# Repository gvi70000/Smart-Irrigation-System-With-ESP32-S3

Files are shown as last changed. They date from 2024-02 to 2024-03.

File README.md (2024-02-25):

Introducing the Smart Irrigation System Controller Board powered by the ESP32-S3!
Water-Automation-PCB-Top

Water-Automation-PCB-Bottom

This hardware combines innovation and efficiency to revolutionize the way you manage your irrigation needs. Equipped with a host of advanced features, including an onboard BMP581 for precise weather data, support for up to 10 valve controls via relays, and seamless serial communication with a VL53L4CX sensor to accurately measure water levels in your well, this controller board is your key to achieving optimal irrigation and conserving valuable resources.

Say goodbye to guesswork and hello to intelligent, data-driven irrigation management, Welcome to the future of smart agriculture.

This feature-packed ESP32-S3-based Smart Irrigation System Controller Board is designed to streamline your irrigation management with unparalleled precision and control.

The board serves as the central hub for your irrigation system, seamlessly connecting and communicating with MQTT servers for efficient operation.

With 10 GPIO pins at your disposal, capable of driving up to 10 relays through 3V3 to 5V level shifters, you can effortlessly control the water flow in your irrigation system. The status of each output is visually presented using dedicated LEDs (L1 to L10 pins), providing real-time feedback to keep you informed.

For manual control of your valves, we've incorporated an analog input to read an array of push buttons. The voltage divider for the button array is thoughtfully designed for easy interfacing and intuitive operation.

The board also integrates Serial Port 1 of the ESP32-S3 to communicate with a VL53L4CX Time-Of-Flight sensor. This sensor plays a crucial role in monitoring water levels in your main reservoir or well, ensuring they remain within safe limits. The communication between the ESP32-S3 and the VL53L4CX is facilitated via an STM32F103 microcontroller, enhancing its capabilities. Notably, the power to the sensor is intelligently managed by the ESP32-S3 program to conserve energy.

To provide comprehensive environmental data, I've included a BMP581 pressure and temperature sensor on the I2C port. This allows you to access essential information such as atmospheric pressure and temperature. Additionally, the I2C port is open for additional device connections, provided that the I2C pull-up resistors are located on this controller board for your convenience.

For situations demanding higher current, the board offers a controlled output switch on S25V, directly connected to the 5V onboard power supply.

When it comes to programming, you have the flexibility to choose between the USB C port or the ESP32-S3 Serial Port 0 (Tx, Rx, 3V3, GND pins), making the process straightforward and accessible.

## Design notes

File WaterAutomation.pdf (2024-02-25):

# Water Automation Control

## Made by Ion Grozea

www.grozeaion.com

# Components

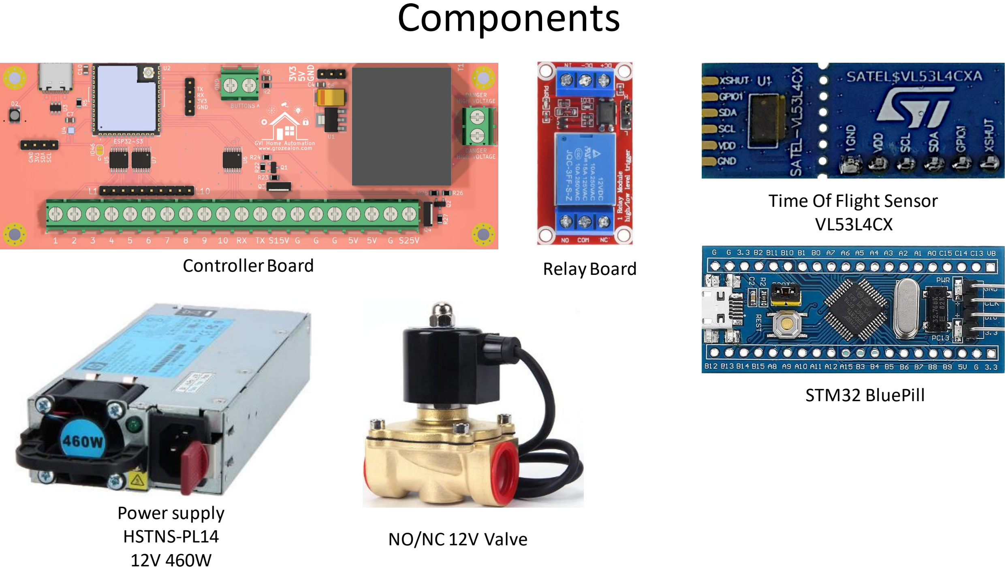
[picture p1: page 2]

Power supply
HSTNS-PL14
12V 460W

NO/NC 12V Valve

Time Of Flight Sensor
VL53L4CX

STM32 BluePill

Controller Board | Relay Board

# Components

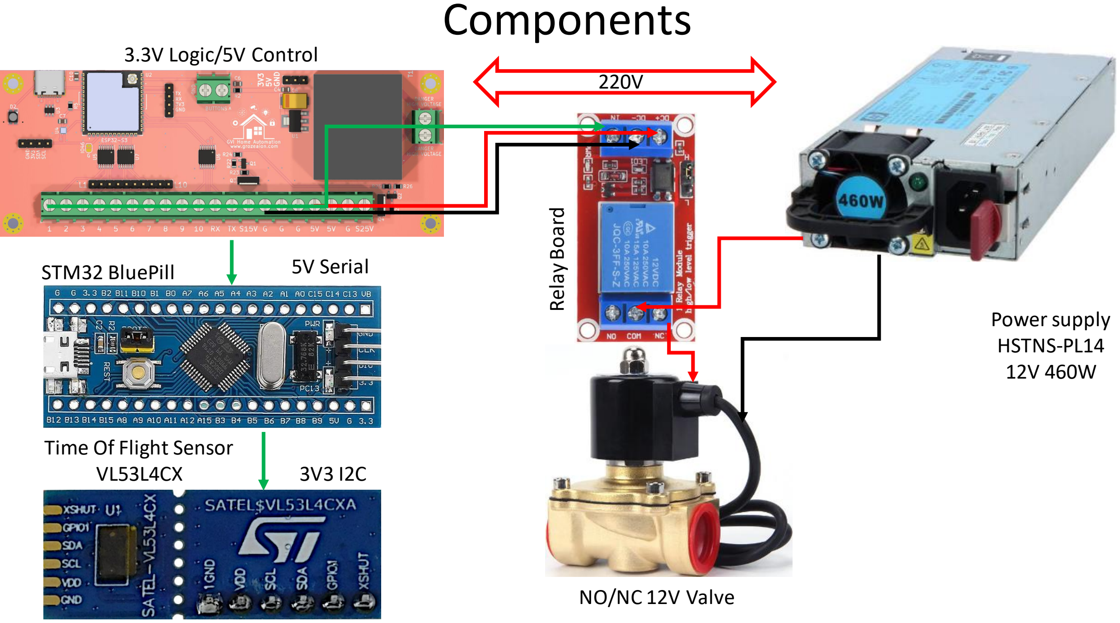
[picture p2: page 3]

Power supply
HSTNS-PL14
12V 460W

NO/NC 12V Valve

Time Of Flight Sensor
VL53L4CX

5V Serial

Relay Board

3.3V Logic/5V Control
220V

STM32 BluePill

3V3 I2C

# Controller PCB Top

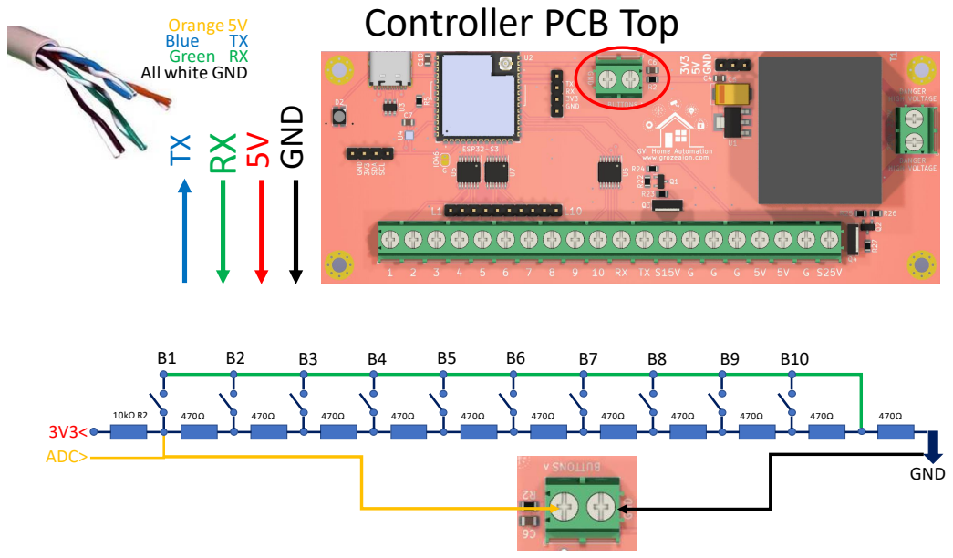
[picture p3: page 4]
GND; Blue; 3V3< ADC>

Orange 5V
Green RX
All white GND

# Controller PCB Top

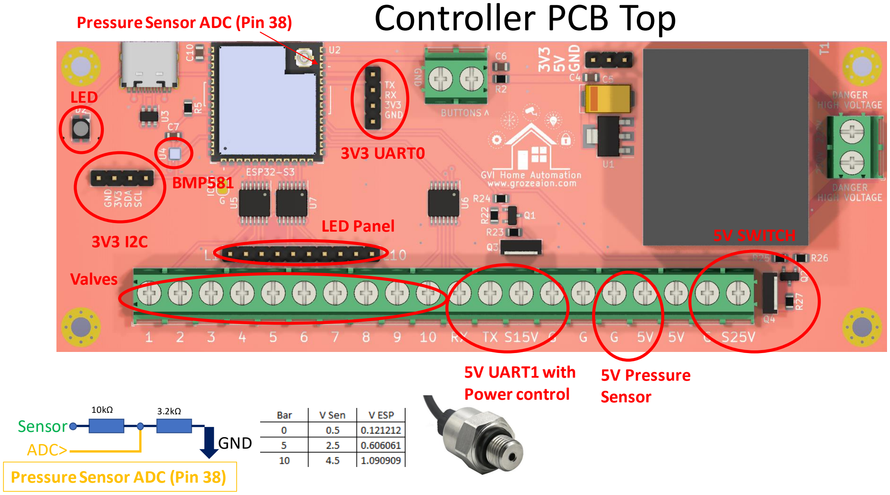
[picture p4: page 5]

3V3 I2C

3V3 UART0
BMP581

LED

LED Panel | 5V SWITCH

Valves

5V UART1 with
Power control
10kΩ | 3.2kΩ
Sensor
ADC> | GND

Pressure Sensor ADC (Pin 38)

Pressure Sensor ADC (Pin 38)

5V Pressure
Sensor

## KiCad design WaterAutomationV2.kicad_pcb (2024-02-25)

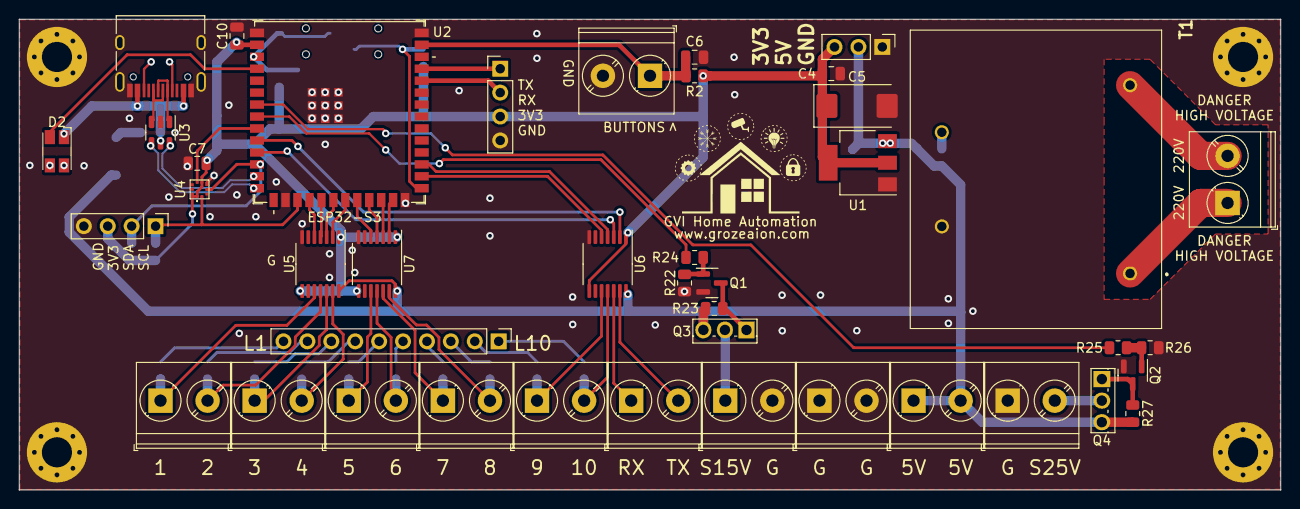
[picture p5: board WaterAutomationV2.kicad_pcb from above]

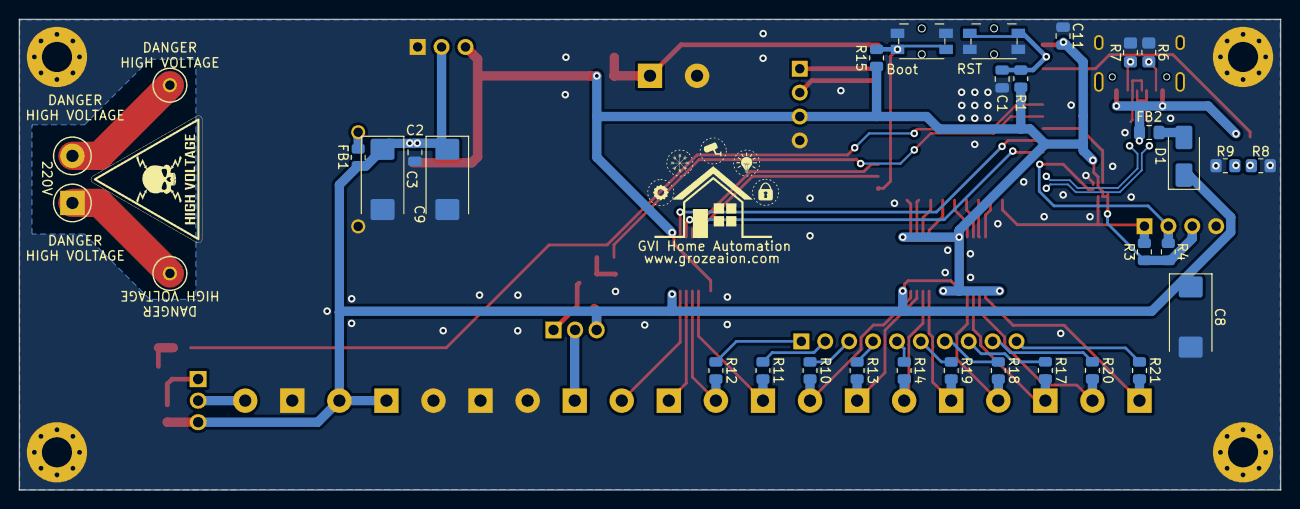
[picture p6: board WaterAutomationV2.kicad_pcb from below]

Board: 2 copper layers, 134.0 x 50.0 mm, 75 parts (29 on the bottom side), 67 nets.

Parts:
C1, C2, C4, C7, C10: 100n; C_0805_2012Metric
C3, C5, C8, C9: 22u; CP_EIA-7343-43_Kemet-X_Pad2.25x2.55mm_HandSolder
C6: C; C_0805_2012Metric
C11: 10u; C_0805_2012Metric
D1: MBRA340; D_SMA
D2: LED_Dual_AKKA; LED_Avago_PLCC4_3.2x2.8mm_CW
FB1: FerriteBead; R_0805_2012Metric
FB2: FerriteBead; C_0805_2012Metric_Pad1.18x1.45mm_HandSolder
H2, H3, H4, H5: MountingHole_Pad; MountingHole_3.2mm_M3_Pad_Via
J1, J3, J5, J7, J9, J10, J11, J13, J15, J17, J19, J20: Screw_Terminal_01x02; TerminalBlock_Phoenix_PT-1,5-2-5.0-H_1x02_P5.00mm_Horizontal
J2, J4: Conn_01x04; PinHeader_1x04_P2.54mm_Vertical
J6: Conn_01x03; PinHeader_1x03_P2.54mm_Vertical
J12: Conn_01x10; PinHeader_1x10_P2.54mm_Vertical
Q1, Q2: BSS138; SOT-23
Q3, Q4: IRFU9024NPBF; TO-251-3_Vertical
R1, R2, R15, R22, R23, R26, R27: 10k; R_0805_2012Metric
R3, R4: 2.2k; R_0805_2012Metric
R6, R7: 5.1k; R_0805_2012Metric_Pad1.20x1.40mm_HandSolder
R8: 100; R_0805_2012Metric_Pad1.20x1.40mm_HandSolder
R9: 220; R_0805_2012Metric_Pad1.20x1.40mm_HandSolder
R10, R11, R12, R13, R14, R17, R18, R19, R20, R21: 220; R_0805_2012Metric
R24, R25: 100; R_0805_2012Metric
SW1: RST; Panasonic_EVQPUM_EVQPUD
SW2: Boot; Panasonic_EVQPUM_EVQPUD
T1: 47152; MYRRA-47121
U1: LD1117S12TR_SOT223; SOT-223-3_TabPin2
U2: ESP32-S3-WROOM-1; ESP32-S3-WROOM-1U
U3: USBLC6-2SC6; SOT-23-6
U4: BMP581
U5, U6, U7: TXS0104E; TSSOP-14_4.4x5mm_P0.65mm
USB1: USB C; USB_C_Receptacle_HRO_TYPE-C-31-M-12

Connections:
+3.3V: C4.1, C5.1, C7.1, C10.1, C11.1, J2.3, J4.3, J6.3, R1.2, R2.1, R3.2, R4.2, R15.1, U1.2 (VO), U2.2 (3V3), U4.1 (VDDIO), U4.6 (CSB), U4.10 (VDD), U5.1 (VCCA), U5.8 (OE), U6.1 (VCCA), U6.8 (OE), U7.1 (VCCA), U7.8 (OE)
+5V: C2.1, C3.1, C8.1, C9.1, D1.1 (K), FB1.1, J6.2, J10.1, J10.2, Q3.3 (SOURCE), Q4.3 (SOURCE), R23.1, R27.1, U1.3 (VI), U5.14 (VCCB), U6.14 (VCCB), U7.14 (VCCB)
+5VD: D2.1 (A1), FB2.1, U3.5 (VBUS), USB1.A4 (VBUS), USB1.A9 (VBUS), USB1.B4 (VBUS), USB1.B9 (VBUS)
BOOT: R15.2, SW2.2, U2.27 (GPIO0/BOOT)
BUTTONS: C6.1, J5.1, R2.2, U2.39 (GPIO1/TOUCH1/ADC1_CH0)
CTRL_SEN1: R24.1, U2.8 (GPIO15/U0RTS/ADC2_CH4/XTAL_32K_P)
CTRL_SEN2: R25.1, U2.7 (GPIO7/TOUCH7/ADC1_CH6)
GND: C1.2, C2.2, C3.2, C4.2, C5.2, C6.2, C7.2, C8.2, C9.2, C10.2, C11.2, H2.1, H3.1, H4.1, H5.1, J1.1, J2.4, J4.4, J5.2, J6.1, J7.1, J7.2, J19.2, Q1.2 (S), Q2.2 (S), R6.1, R7.1, R8.1, R9.1, R22.1, R26.1, SW1.2, SW2.1, T1.9 (DC_OUTPUT_0V), U1.1 (GND), U2.1 (GND), U2.16 (GPIO46), U2.26 (GPIO45), U2.40 (GND), U2.41 (GND), U3.2 (GND), U4.3 (VSS_1), U4.5 (SDO), U4.8 (VSS_2), U4.9 (VSS_3), U5.7 (GND), U6.7 (GND), U7.7 (GND), USB1.A1 (GND), USB1.A12 (GND), USB1.B1 (GND), USB1.B12 (GND), USB1.S1 (Shell1)
INT: U2.9 (GPIO16/U0CTS/ADC2_CH5/XTAL_32K_N), U4.7 (INT)
LED: D2.4 (A2), U2.4 (GPIO4/TOUCH4/ADC1_CH3)
unnamed: D1.2 (A), FB2.2
unnamed: D2.2 (K1), R9.2
unnamed: D2.3 (K2), R8.2
unnamed: J3.1, T1.1 (AC_OR_DC_INPUT_1)
unnamed: J3.2, T1.5 (AC_OR_DC_INPUT_2)
unnamed: J12.1, R12.1
unnamed: J12.2, R11.1
unnamed: J12.3, R10.1
unnamed: J12.4, R13.1
unnamed: J12.5, R14.1
unnamed: J12.6, R19.1
unnamed: J12.7, R18.1
unnamed: J12.8, R17.1
unnamed: J12.9, R20.1
unnamed: J12.10, R21.1
unnamed: Q1.3 (D), Q3.1 (GATE), R23.2
unnamed: Q1.1 (G), R22.2, R24.2
unnamed: Q2.3 (D), Q4.1 (GATE), R27.2
unnamed: Q2.1 (G), R25.2, R26.2
unnamed: FB1.2, T1.7 (DC_OUTPUT_+V)
unnamed: U3.1 (I/O1), USB1.A7 (D-), USB1.B7 (D-)
unnamed: U3.3 (I/O2), USB1.A6 (D+), USB1.B6 (D+)
unnamed: R7.2, USB1.A5 (CC1)
unnamed: R6.2, USB1.B5 (CC2)
O1: J9.1, R21.2, U5.10 (B4)
O2: J9.2, R20.2, U5.11 (B3)
O3: J11.1, R17.2, U5.12 (B2)
O4: J11.2, R18.2, U5.13 (B1)
O5: J13.1, R19.2, U7.10 (B4)
O6: J13.2, R14.2, U7.11 (B3)
O7: J15.1, R13.2, U7.12 (B2)
O8: J15.2, R10.2, U7.13 (B1)
O9: J17.1, R11.2, U6.10 (B4)
O10: J17.2, R12.2, U6.11 (B3)
PWR_SEN1: J19.1, Q3.2 (DRAIN)
PWR_SEN2: J1.2, Q4.2 (DRAIN)
RST: C1.1, R1.1, SW1.1, U2.3 (EN)
RX0: J2.2, U2.36 (U0RXD/GPIO44/CLK_OUT2)
RX1: U2.11 (GPIO18/U1RXD/ADC2_CH7/CLK_OUT3), U6.3 (A2)
RX05: J20.1, U6.12 (B2)
SCL: J4.1, R3.1, U2.17 (GPIO9/TOUCH9/ADC1_CH8/FSPIHD/SUBSPIHD), U4.2 (SCK)
SDA: J4.2, R4.1, U2.12 (GPIO8/TOUCH8/ADC1_CH7/SUBSPICS1), U4.4 (SDI)
TX0: J2.1, U2.37 (U0TXD/GPIO43/CLK_OUT1)
TX1: U2.10 (GPIO17/U1TXD/ADC2_CH6), U6.2 (A1)
TX05: J20.2, U6.13 (B1)
USB_D+: U2.14 (GPIO20/U1CTS/ADC2_CH9/CLK_OUT1/USB_D+), U3.4 (I/O2)
USB_D-: U2.13 (GPIO19/U1RTS/ADC2_CH8/CLK_OUT2/USB_D-), U3.6 (I/O1)
V1: U2.18 (GPIO10/TOUCH10/ADC1_CH9/FSPICS0/FSPIIO4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), U5.5 (A4)
V2: U2.19 (GPIO11/TOUCH11/ADC2_CH0/FSPID/FSPIIO5/S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), U5.4 (A3)
V3: U2.20 (GPIO12/TOUCH12/ADC2_CH1/FSPICLK/FSPIIO6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), U5.3 (A2)
V4: U2.21 (GPIO13/TOUCH13/ADC2_CH2/FSPIQ/FSPIIO7/S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), U5.2 (A1)
V5: U2.22 (GPIO14/TOUCH14/ADC2_CH3/FSPIWP/FSPIDQS/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), U7.5 (A4)
V6: U2.23 (GPIO21), U7.4 (A3)
V7: U2.24 (GPIO47/SPICLK_P/SUBSPICLK_P_DIFF), U7.3 (A2)
V8: U2.25 (GPIO48/SPICLK_N/SUBSPICLK_N_DIFF), U7.2 (A1)
V9: U2.28 (SPIIO6/GPIO35/FSPID/SUBSPID), U6.5 (A4)
V10: U2.29 (SPIIO7/GPIO36/FSPICLK/SUBSPICLK), U6.4 (A3)

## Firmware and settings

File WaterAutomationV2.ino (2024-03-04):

#include <Wire.h>
#include <EEPROM.h>
#include <WiFi.h>
#include <PubSubClient.h>
#include "SparkFun_BMP581_Arduino_Library.h"

// Use it for printing messages
//#define DEBUG

// If we use the water pressure sensor to monitor pressure and leaks
//#define HAS_PRESSURE

// Control valve if a leak is detected
//#define HAS_LEAK_CONTROL

#if defined DEBUG
   #define debug_begin(x) Serial.begin(x)
   #define debug(x)       Serial.print(x)
   #define debugln(x)     Serial.println(x)
#else
   #define debug_begin(x)
   #define debug(x)
   #define debugln(x)
#endif

// We have 3 or 4 sensors?
#ifdef HAS_PRESSURE
  constexpr uint8_t SENSORS_NO      = 4;
#else
  constexpr uint8_t SENSORS_NO      = 3;
#endif

// 388 bytes for calibration, 1 byte for C(alibration), 1 byte checksum, 2 bytes start/end message marker
// 388 bytes for calibration, 1 byte for C(alibration), 1 byte checksum, 2 bytes start/end message marker
constexpr uint16_t CALIB_DATA_LEN   = 388;
// Buffer length Tx and Rx
constexpr uint16_t BUFFER_LEN	= CALIB_DATA_LEN + 4;
// Max. no. of devices
constexpr uint8_t DEV_MAX           = 10;
// Where in EEPROM we start to store calibration data
constexpr uint8_t CAL_START         = DEV_MAX + 1; // Pos 11
// Where in EEPROM we stop to store calibration data
constexpr uint16_t CAL_END          = CAL_START + CALIB_DATA_LEN; // Pos 38

// Used in serial communication with VL sensor
constexpr uint8_t START_MARKER		  = 60; // < Start marker for serial
constexpr uint8_t END_MARKER			  = 62; // > End marker for serial
constexpr uint8_t CMD_CALIBRATE		  =	67; // Send C to start calibration
constexpr uint8_t CMD_STORE_CAL		  =	83; // Send S to store calibration data we send

constexpr uint8_t RESPONSE_LENGTH	  = 76; // Get L to inform about length data
constexpr uint8_t RESPONSE_CAL_DONE	= 67; // Get C to inform about calibration data
constexpr uint8_t RESPONSE_FAIL		  = 70; // Get F to indicate something went wrong
constexpr uint8_t RESPONSE_OK			  = 83; // CMD_STORE_CAL // Get S to indicate something went OK

#ifdef HAS_PRESSURE
// 4.5v 4,7k 1.47k 1.072V
  //constexpr float ADC_FACTOR      0.000805664062f
  constexpr float VOLT_TO_BAR_F1    = 0.008308813477f; // This is 10.313f * ADC_FACTOR
  constexpr float VOLT_TO_BAR_F2    = 1.25f;
  constexpr uint8_t PRESS_PIN       = 2; // Analog read Pressure
  // R1 = 9.95, R2=3.264 => 1.112V from 4.5V
  // P = 0.0024 * ADC
#endif
// Pins used
constexpr uint8_t BTN_PIN           = 1; // Analog read buttons
constexpr uint8_t LED_PIN           = 4;
constexpr uint8_t LEVEL_PIN         = 7;
constexpr uint8_t CTRL_PIN2         = 15;

// WiFi Connect period in ms
constexpr uint16_t UART_SPEED        = 9600;
// WiFi Connect period in ms
constexpr uint16_t WiFi_Period       = 1000;
// Send data to MQTT brocker every 30 seconds
constexpr uint16_t mqttPeriod       = 10; 
// Min. water level in the well in m
constexpr float minWellLevel        = 0.5;
// Delay for MQTT functions
constexpr uint8_t delayMQTT         = 50;
// WiFi Connect period
constexpr uint16_t VL53L4CX_WAIT    = 6000;
// Debounce time in milliseconds
constexpr uint8_t DEBOUNCE_DELAY    = 100;

// ADC Values for buttons 1 to 10
constexpr uint16_t BTN_ADC_MIN[] = {430, 870, 1280, 1650, 1990, 2315, 2615, 2895, 3155, 3400};
constexpr uint16_t BTN_ADC_MAX[] = {470, 830, 1320, 1690, 2030, 2355, 2655, 2935, 3195, 3440};

enum Button { None, Btn1, Btn2, Btn3, Btn4, Btn5, Btn6, Btn7, Btn8, Btn9, Btn10 };
enum DeviceStatus { Off, On };
enum SensorNumber { Level, Temp, Press, WaterPress};

typedef struct ButtonObject {
  const char* topicState;
  const char* topicTime;
  uint8_t pin;
  uint8_t pinState;
  uint8_t timeTarget;
  volatile uint16_t timeSeconds;
};

typedef struct SensorObject {
  const char* name;
  float val;
};

#ifdef HAS_LEAK_CONTROL
  ButtonObject myBackUp[2];
#endif
ButtonObject myDevices[DEV_MAX];
SensorObject mySensors[SENSORS_NO];

// MQTT Server IP
const char* mqtt_server		= "XXX.XXX.XXX.XXX";
// MQTT Server username
const char* mqtt_username	= "MQTT_USER";
// MQTT Server password
const char* mqtt_password = "MQTT_PASSWORD";
// Client name
const char* clientID      = "Valves";
// Number of devices to be used
const char* maxDevNo      = "water/MaxDevNo";
// Calibration topic
constexpr char *topic_CalDist = "Level/Calibrate";
#ifdef HAS_LEAK_CONTROL
  // Leak alarm topic
  constexpr char *topic_LeakAlarm = "water/LeakAlarm";
  // Pressure drop value for alarm in Bar
  constexpr char *topic_LeakValue = "water/LeakValue";
#endif
// MQTT Server port
constexpr uint16_t MQTT_Port   = 1883;

volatile uint8_t interruptBMP = 0;

// Array stored in RTC memory to hold:
// 0-9 Time for each device in Min, 10 Maximum number of devices used
uint8_t DEV_IN_USE = 1;

// Stores the time when the sensors must be read
volatile uint16_t mqttTime;

// Current button
uint8_t crtButton = None;
// Timer
hw_timer_t * timer = NULL;
// Calibration Distance
uint8_t calibrateDistance = 0;
// Used for timeout
uint32_t timeCheck;
#ifdef HAS_LEAK_CONTROL
  // Store the alarm status
  uint8_t alarmLeak = 0;
  // Store the last pressure reading
  float prevPressureVal = 0.0f;
  // If pressure drops with 1 Bar the alarm is raised
  float pressureThreshold = 1.0f; 
#endif

BMP581 pressureSensor;
WiFiClient wifi_Client;
PubSubClient mqtt_Client(wifi_Client);

// Interrupt callback function for timer
void IRAM_ATTR onTimer() {
  mqttTime++;
  for (int cnt = 0; cnt < DEV_IN_USE; cnt++) {
    // If the device is On, increment the timer
    if(myDevices[cnt].pinState) {
      myDevices[cnt].timeSeconds++;
    }
  }
}

// Interrupt callback function for BMP581
void bmp581InterruptHandler() {
  interruptBMP = 1;
}

void sendToSTM(const uint8_t msgType) {
  uint16_t txLen = 4;
  // Determine the message length and fill the buffer based on message type
  if(msgType == CMD_STORE_CAL) {
    txLen = BUFFER_LEN;
  }
  uint8_t txBuffer[txLen];
  // Initialize the common header for all messages
  txBuffer[0] = START_MARKER;
  txBuffer[1] = msgType;
  uint8_t checkSum = msgType;
  if(msgType == CMD_STORE_CAL) {
    for (uint16_t cnt = CAL_START; cnt < CAL_END; cnt++) {
      uint16_t tmp = cnt - 9;
      txBuffer[tmp] = EEPROM.read(cnt);
      checkSum += txBuffer[tmp];
    }
  }
  // Add checksum and end marker
  txBuffer[txLen - 2] = checkSum;
  txBuffer[txLen - 1] = END_MARKER;
  // Send the message
  Serial1.write(txBuffer, txLen);
}

uint8_t ProcessReceivedMessage() {
  digitalWrite(LED_PIN, LOW);
  uint8_t retunValue = 0;
  // If we have 4 bytes in the buffer and the first one is <
  if((Serial1.available() > 3) && (Serial1.read() == START_MARKER)) {
    // Get the message type
    uint8_t msgType = Serial1.read();
    // Keep in mind that we already read 2 bytes
    // Depending on message type we need to wait for some more bytes
    uint16_t expectedMsgLen = 0; 
    // expectedMsgLen in below switch is ignoring the last 2 bytes we receive
    switch(msgType) {
      case RESPONSE_LENGTH: // We get 6 bytes in total
        expectedMsgLen = 2;
      break;
      case RESPONSE_CAL_DONE: // We get 392 bytes in total
        expectedMsgLen = CALIB_DATA_LEN;
      break;
      default: // RESPONSE_OK, RESPONSE_FAIL // We get 4 bytes in total
        expectedMsgLen = 0;
      break;
    }

    uint8_t receivedCheckSum = 0;
    // If we get a 4 byte message < M M >
    // The third byte we read is the checkSum
    if(!expectedMsgLen) {
      receivedCheckSum = Serial1.read();
      if(receivedCheckSum == msgType) {
        retunValue = msgType;
      }
    } else {
      // Wait to receive all bytes or return timeout
      timeCheck = millis();
      while(Serial1.available() < expectedMsgLen) {
        // If we have a timeout, exit the function
        if((millis() - timeCheck) > VL53L4CX_WAIT) {
          // Reuse timeCheck 
          timeCheck = 0;
          break;
        }
      }
      // If we do not have a timeout
      if(timeCheck) {
        // Buffer to hold received values, START_MARKER not included
        uint8_t rxBuffer[expectedMsgLen];
        // Add message type as it is needed in check sum calculation
        uint8_t checksum = msgType;
        // Add all bytes in the buffer and calculate check sum in the same loop
        for (uint16_t i = 0; i < expectedMsgLen; i++) {
          rxBuffer[i] = Serial1.read();
          // Calculate the check sum
          checksum += rxBuffer[i];
          // Serial.print(i); Serial.print(">>>"); Serial.println(rxBuffer[i]);
        }
        // By now we have received the last 2 bytes
        receivedCheckSum = Serial1.read();
        // Do not check for > end marker as we test the check sum 
        // Check message validity
        if (checksum == receivedCheckSum) {
          // What type of message we have?
          switch (msgType) {
            case RESPONSE_OK:
              retunValue = RESPONSE_OK;
            break;
            case RESPONSE_FAIL:
              // Handle failure response
              retunValue = RESPONSE_FAIL;
            break;
            case RESPONSE_LENGTH:
              // Process length data
              {
              mySensors[Level].val = (float)*(uint16_t*)&rxBuffer[0];
              retunValue = RESPONSE_LENGTH;
              }
            break;
            case RESPONSE_CAL_DONE:
            {
              // Process calibration data. From 0 to DEV_MAX we have the device data
              for(uint16_t cnt = CAL_START; cnt < CAL_END; cnt++) {
                EEPROM.write(cnt, rxBuffer[cnt - CAL_START]);
                // Serial.print(cnt);Serial.print("---");Serial.print(cnt - CAL_START);
                // Serial.print("---");Serial.println(rxBuffer[cnt - CAL_START]); 
              }
              // No need to wait after commit
              EEPROM.commit();
              retunValue = RESPONSE_CAL_DONE;
            }
            break;
          } // End switch
        } // End CheckSum check
      } // End timeout check
    } // End longer message check
  }
  digitalWrite(LED_PIN, HIGH);
  Serial1.flush();
  return retunValue;
}

// Signal errors error
void ledSignal(uint8_t err) {
  // Delay for MQTT functions
  constexpr uint8_t stateDelay = 250;
  uint8_t blinkCnt = 0;
  switch(err) {
    case 1:
      blinkCnt = 3;
      break;
    case 2:
      blinkCnt = 4;
      break;
    default:
      blinkCnt = 2;
  }
  for(uint8_t c = 0; c < blinkCnt; c++){
    digitalWrite(LED_PIN, HIGH);
    delay(stateDelay);
    digitalWrite(LED_PIN, LOW);
    delay(stateDelay);
  }
}

void writeDefaultEEPROM() {
  for(uint8_t cnt = 0; cnt < DEV_MAX; cnt++) {
    EEPROM.write(cnt, 0);
  }
  EEPROM.write(DEV_MAX, 1);
  EEPROM.commit();
  delay(delayMQTT);
}

void setup() {
  constexpr uint8_t TX1_PIN = 17;
  constexpr uint8_t RX1_PIN = 18;
  analogSetAttenuation(ADC_2_5db);
  analogReadResolution(12);
  Serial1.begin(UART_SPEED, SERIAL_8N1, RX1_PIN, TX1_PIN);
  #ifdef DEBUG
    debug_begin(UART_SPEED);
  #endif
  // Serial.begin(9600);
  EEPROM.begin(CAL_END);
  // writeDefaultEEPROM();
  pinMode(LED_PIN, OUTPUT);
  pinMode(LEVEL_PIN, OUTPUT);
  pinMode(CTRL_PIN2, OUTPUT);
  digitalWrite(LED_PIN, LOW);
  // Level pin not used. The VL sensor is powerd all the time
  digitalWrite(LEVEL_PIN, LOW);
  digitalWrite(CTRL_PIN2, LOW);
  // Initialize valves and sensors
  initObjects();
  // Load number of devices from EEPROM
  DEV_IN_USE = EEPROM.read(DEV_MAX);
  Serial1.flush();
  // Wait for STM board to wakeUp. Getting here takes 115ms
  while((millis() - timeCheck) < VL53L4CX_WAIT) {
    if(ProcessReceivedMessage()) break;
    delay(5);
  }
  // Now send the calibration data
  sendToSTM(CMD_STORE_CAL);

  // // Setup BMP581 temperature and pressure sensor
  bmpInit();
  // Setup and connect to WiFi
  startWiFi();
  // Set MQTT server IP and port
  mqtt_Client.setServer(mqtt_server, MQTT_Port);
  // Attach the MQTT callback function
  mqtt_Client.setCallback(mqttCallback);
  // Connect to MQTT broker
  ConnectToMQTT();
  if (!mqtt_Client.connected()) {
    mqtt_reconnect();
  }
  // Timer initialization
  // Set timer frequency to 1Mhz (default timer frequency is 80MHz)
  timer = timerBegin(0, 80, true);
  // Attach onTimer function to our timer.
  timerAttachInterrupt(timer, &onTimer, true);
  // Set alarm to call onTimer function every second (value in microseconds).
  // Repeat the alarm (third parameter) with unlimited count = 0 (fourth parameter).
  timerAlarmWrite(timer, 1000000, true);
  timerAlarmEnable(timer);
  ledSignal(0);
  crtButton = None;
}

void loop() {
  // // Used to check ADC values
  // if (mqttTime >= mqttPeriod) {
  //   uint16_t adc_val = analogRead(BTN_PIN);
  //   debugln(adc_val);
  //   mqttTime = 0;
  // }
  yield();
  ProcessReceivedMessage();
  mqtt_Client.loop();
  // Is any button pressed?
  getButtons();
  if (crtButton) {
    uint8_t tmp = crtButton - 1;
    crtButton = None;
    // Accept button press events only for devices that are used
    if(tmp < DEV_IN_USE) {
      // Is the device already turned ON?
      if(myDevices[tmp].pinState) {
        // If a button is pressed and device is ON then turn off the device, set the time and publish MQTT
        deviceOnOff(tmp, Off, 1);
      } else {
        // If a button is pressed turn on the device, set the time and publish MQTT
        deviceOnOff(tmp, On, 1);
      }
    }
  }

  // Check if any device needs to be turned Off
  for (uint8_t cnt = 0; cnt < DEV_IN_USE; cnt++) {
    // Target time is in Minutes, START_MARKER has a value of 60, so...
    // If timeSeconds is not 0 and timeSeconds is equal or larger than target time in seconds
    if ((myDevices[cnt].timeSeconds) && (myDevices[cnt].timeSeconds >= (myDevices[cnt].timeTarget * START_MARKER))) {
      deviceOnOff(cnt, Off, 1);
    }
  }
  // Read temperature, pressure and water level
  if (mqttTime >= mqttPeriod) {
    #ifdef HAS_PRESSURE
      // Get data from Analog pressure sensor
      getWaterPressure();
    #endif
    // Get data from onboard BMP581
    getTempPress();
    // Check if we have new data from VL53L4CX
    ProcessReceivedMessage();
    // Publish the topics
    publishSensors();
    // If water level is too low turn Off all devices, set the time to 0 and publish MQTT
    if (mySensors[Level].val <= minWellLevel) {
      for (int cnt = 0; cnt < DEV_IN_USE; cnt++) {
        deviceOnOff(cnt, Off, 1);
      }
    }
    mqttTime = 0;
  }
  // Check if calibration was requested
  if(calibrateDistance) {
    // Send request to STM board
    sendToSTM(CMD_CALIBRATE);
    // Wait for reply
    delay(VL53L4CX_WAIT);
    // If calibration is OK
    if(ProcessReceivedMessage() == RESPONSE_CAL_DONE){
      publishToMqtt(topic_CalDist, "1");
    } else {
      publishToMqtt(topic_CalDist, "0");
    }
    calibrateDistance = 0;
  }
}

#ifdef HAS_PRESSURE
  // Voltage divider 10k/3.2k
  // V_In max = 4.5V, V_Div = 1.09V
  // P = 0 Bar V = 0.121V
  // P = 5 Bar V = 0.606V
  // P = 10 Bar V = 1.09
  // P = 10.313*V - 1.25
  void getWaterPressure() {
    // Transform ADC reading in volts
    //float voltage = (float)adc1_get_raw(ADC1_CHANNEL_1) * ADC_FACTOR;
    // Transform voltage in Bar
    mySensors[WaterPress].val = (float)analogRead(PRESS_PIN) * VOLT_TO_BAR_F1 + VOLT_TO_BAR_F2;
    #ifdef HAS_LEAK_CONTROL
      if((mySensors[WaterPress].val - prevPressureVal) > pressureThreshold) {
        digitalWrite(LEVEL_PIN, HIGH);
        alarmLeak = 1;
        myBackUp[0] = myDevices[0];
        myBackUp[1] = myDevices[1];
        // Cut off water supply. Valve 0 NC and 1 NO    
        myDevices[0].pinState = 0;
        publishToMqtt(myDevices[0].topicState, String(myDevices[0].pinState));
        digitalWrite(myDevices[0].pin, myDevices[0].pinState);
        myDevices[1].pinState = 1;
        publishToMqtt(myDevices[1].topicState, String(myDevices[1].pinState));
        digitalWrite(myDevices[1].pin, myDevices[1].pinState);
        publishToMqtt(topic_LeakAlarm, "1");
      } else {
        // If the alarm is no longer valid
        if(alarmLeak) {
          digitalWrite(LEVEL_PIN, LOW);
          alarmLeak = 0;
          myDevices[0] = myBackUp[0];
          publishToMqtt(myDevices[0].topicState, String(myDevices[0].pinState));
          digitalWrite(myDevices[0].pin, myDevices[0].pinState);
          myDevices[1] = myBackUp[1];
          publishToMqtt(myDevices[1].topicState, String(myDevices[1].pinState));
          digitalWrite(myDevices[1].pin, myDevices[1].pinState);
          publishToMqtt(topic_LeakAlarm, "0");
        }
      }
      prevPressureVal = mySensors[WaterPress].val;
    #endif
  }
#endif

// Function to debounce the button
void getButtons() {
  uint16_t adc_val = analogRead(BTN_PIN);
  crtButton = None;
  // Reset current button if adc_val is greater than a threshold
  if (adc_val > BTN_ADC_MAX[9]) {
    return;
  } else {
    delay(DEBOUNCE_DELAY);
    adc_val = analogRead(BTN_PIN);
    for (uint8_t cnt = 0; cnt < DEV_MAX; cnt++) {
      if((adc_val > BTN_ADC_MIN[cnt]) && (adc_val < BTN_ADC_MAX[cnt])) {
        crtButton = (cnt + 1);
        return;
      }
    }
  }
}

//Turns On or Off a device and updates MQTT topic
void deviceOnOff(uint8_t idx, uint8_t State, uint8_t sendMessage) {
  myDevices[idx].pinState = State;
  // If the state is On
  if (State) {
    digitalWrite(myDevices[idx].pin, HIGH);
  } else {
    digitalWrite(myDevices[idx].pin, LOW);
  }
  myDevices[idx].timeSeconds = 0; // resetTimer
  if (sendMessage) {
    publishToMqtt(myDevices[idx].topicState, String(myDevices[idx].pinState));
  }
}

//Publish value to MQTT topic
void publishToMqtt(const char* mqtt_topic, String mqtt_value) {
  if (!mqtt_Client.publish(mqtt_topic, mqtt_value.c_str())) {
    mqtt_Client.connect(clientID, mqtt_username, mqtt_password);
    delay(delayMQTT);
    mqtt_Client.publish(mqtt_topic, mqtt_value.c_str());
  }
  delay(delayMQTT);
}

void publishTopics() {
  // Publis and subscribe for each valve
  for (uint8_t cnt = 0; cnt < DEV_IN_USE; cnt++) {
    publishToMqtt(myDevices[cnt].topicState, String(myDevices[cnt].pinState));
    delay(delayMQTT);
    mqtt_Client.subscribe(myDevices[cnt].topicState);
    delay(delayMQTT);
    publishToMqtt(myDevices[cnt].topicTime, String(myDevices[cnt].timeTarget));
    delay(delayMQTT);
    mqtt_Client.subscribe(myDevices[cnt].topicTime);
    delay(delayMQTT);
  }

  #ifdef HAS_LEAK_CONTROL
    publishToMqtt(topic_LeakAlarm, "0");
    delay(delayMQTT);
    mqtt_Client.subscribe(topic_LeakAlarm);
    delay(delayMQTT);
    publishToMqtt(topic_LeakValue, String(pressureThreshold));
    delay(delayMQTT);
    mqtt_Client.subscribe(topic_LeakValue);
    delay(delayMQTT);
  #endif

  // Publish/subscribe the calibration Distance, should be 0
  publishToMqtt(topic_CalDist, String(calibrateDistance));
  delay(delayMQTT);
  mqtt_Client.subscribe(topic_CalDist);
  delay(delayMQTT);
}

void publishSensors() {
  for (uint8_t cnt = 0; cnt < SENSORS_NO; cnt++) {
    publishToMqtt(mySensors[cnt].name, String(mySensors[cnt].val));
  }
}

// Connect to MQTT brocker
void ConnectToMQTT() {
  if (mqtt_Client.connect(clientID, mqtt_username, mqtt_password)) {
    publishSensors();
    publishTopics();
    publishToMqtt(maxDevNo, String(DEV_IN_USE));
    delay(delayMQTT);
    mqtt_Client.subscribe(maxDevNo);
  } else {
    ledSignal(2);
  }
}

//Reconnect to MQTT brocker
void mqtt_reconnect() {
  uint8_t retry = 10;
  while (!mqtt_Client.connected() && retry) {
    ConnectToMQTT();
    retry--;
  }
}

void setNewDevNo() {
  EEPROM.write(DEV_MAX, DEV_IN_USE);
  EEPROM.commit();
  for(uint8_t cnt = DEV_IN_USE; cnt < DEV_MAX; cnt++) {
    deviceOnOff(cnt, Off, 0);
    mqtt_Client.unsubscribe(myDevices[cnt].topicState);
    mqtt_Client.unsubscribe(myDevices[cnt].topicTime);
    delay(delayMQTT);
  }
  // To update the devices
  publishTopics();
}
// MQTT callback function
void mqttCallback(char* topic, byte* payload, unsigned int length) {
  debug("Message arrived [");
  debug(topic);
  debugln("]");
  
  String messageTemp;
  for (int i = 0; i < length; i++) {
    messageTemp += (char)payload[i];
  }
  // If we get calibration value of 1
  if (strcmp(topic, topic_CalDist) == 0) {
    calibrateDistance = messageTemp.toInt();
  }
  #ifdef HAS_LEAK_CONTROL
  if (strcmp(topic, topic_LeakValue) == 0) {
    pressureThreshold = messageTemp.toFloat();
  }
  #endif
  // If we change the number of devices
  if (strcmp(topic, maxDevNo) == 0) {
    DEV_IN_USE = messageTemp.toInt();
    if(DEV_IN_USE > DEV_MAX) DEV_IN_USE = DEV_MAX;
    if(DEV_IN_USE < 1) DEV_IN_USE = 1;
    setNewDevNo();
  } else {
    for (uint8_t cnt = 0; cnt < DEV_IN_USE; cnt++) {
      // If the device state is changed
      if (strcmp(topic, myDevices[cnt].topicState) == 0) {
        myDevices[cnt].pinState = messageTemp.toInt();
        deviceOnOff(cnt, myDevices[cnt].pinState, 0);
      }
      // If the device time is changed
      if (strcmp(topic, myDevices[cnt].topicTime) == 0) {
        myDevices[cnt].timeTarget = messageTemp.toInt();
        EEPROM.write(cnt, myDevices[cnt].timeTarget);
        EEPROM.commit();
        delay(delayMQTT);
      }
    }
  }
}

// Wi-Fi connection SetUp - Wasted a day with connection issues because of buggy library
void startWiFi() {
  // WiFi network name
  constexpr char *ssid = "WIFI_NETWORK_NAME";
  // WiFi network password
  constexpr char *password = ""WIFI_NETWORK_PASSWORD";
  WiFi.mode(WIFI_STA);
  WiFi.hostname(clientID);
  // debugln(WiFi.macAddress());
  WiFi.useStaticBuffers(true);
  // WiFi.setMinSecurity(WIFI_AUTH_WPA_PSK);   //WIFI_AUTH_WEP
  WiFi.disconnect();
  delay(WiFi_Period);
  WiFi.begin(ssid, password);
  // Wait to connect to WiFi 
  // WiFi.waitForConnectResult(1000);
  while (WiFi.waitForConnectResult(WiFi_Period) != WL_CONNECTED) {
    ledSignal(1);
  }
}
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
